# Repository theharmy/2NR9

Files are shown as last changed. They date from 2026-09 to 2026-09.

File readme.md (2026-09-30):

# TwoNr9 (2NR9) is a minimalistic ergonomic 20% Keyboard. 

[Pictures by Purox/Nex](https://ncxy.de/)
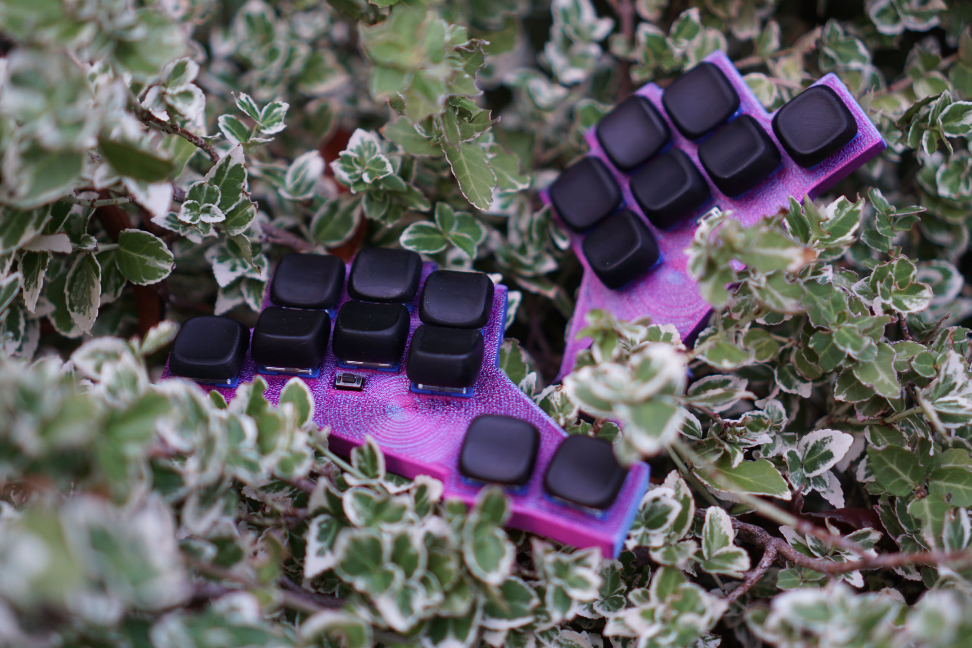
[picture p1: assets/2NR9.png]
2NR9
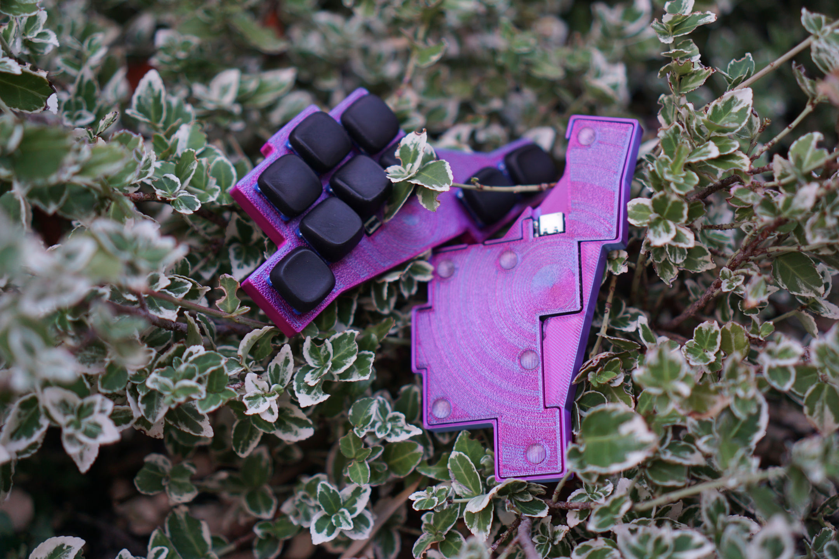
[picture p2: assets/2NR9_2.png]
2NR9_2


## Files In this Repo 
- The PROD files as ZIP as well as a folder, the Kicad PCB File 
- CASE (To-Do)

## Features: 
- 18 Keys with an Minimalistic  Design and Case
- The Case offers hidden Magnet sockets for Magsafe Compability
- Switches: Choc V2 Hotswap 
- MCU: N!N (or Clones)
- battery: 301230 3.7V 110mAh Lipo Battery
  - only this one works due to size Constraints.
- Designed Together with [Purox/Nex](https://ncxy.de/)

### Note 
~~BOTTOM MIDDLE FINGER AND THE PINKY NEED A BODGE WIRE DUE TO WRONGLY FLIPPED HOTSWAP SOCKETS.~~

The Pads for the pinky and bottom middle finger might look odd due to small changes in size, that prevents a bodge wire and should not influence the functionality. 

## ZMK Config: 
- There is a [Blanc Version of the Config](https://github.com/theharmy/zmk-config-twonr9--blank)
- My personal [Config](https://github.com/theharmy/zmk-config), (AI CODE WARNING)
	- with [SRHT by Apfel](https://codeberg.org/apfel)  (A Germlish 2Alpha Layout with Bigrams)
	- and many features of [Urob's ZMK Config](https://github.com/urob/zmk-config) 

### Acknowledgements
- Big Thanks and Much love to 
	- [Purox/Nex](https://ncxy.de/) for a lot of test-printing with me, PCB Design-Support and Feedback.
		- Their: 
			- [Blog](https://ncxy.de/) 
			- [Keyboard Work](https://git.clacktal.es/purox)
			- [Github](https://github.com/ThePurox)
	- Kilipan/Apfel for Getting me Into the 20% Madness, Creation of the SRHT Layout, Patience and Input
		- their:
			- [Codeberg](https://codeberg.org/apfel), for general projects
			- [clacktal.es](https://git.clacktal.es/apfel), for keyboard-related things

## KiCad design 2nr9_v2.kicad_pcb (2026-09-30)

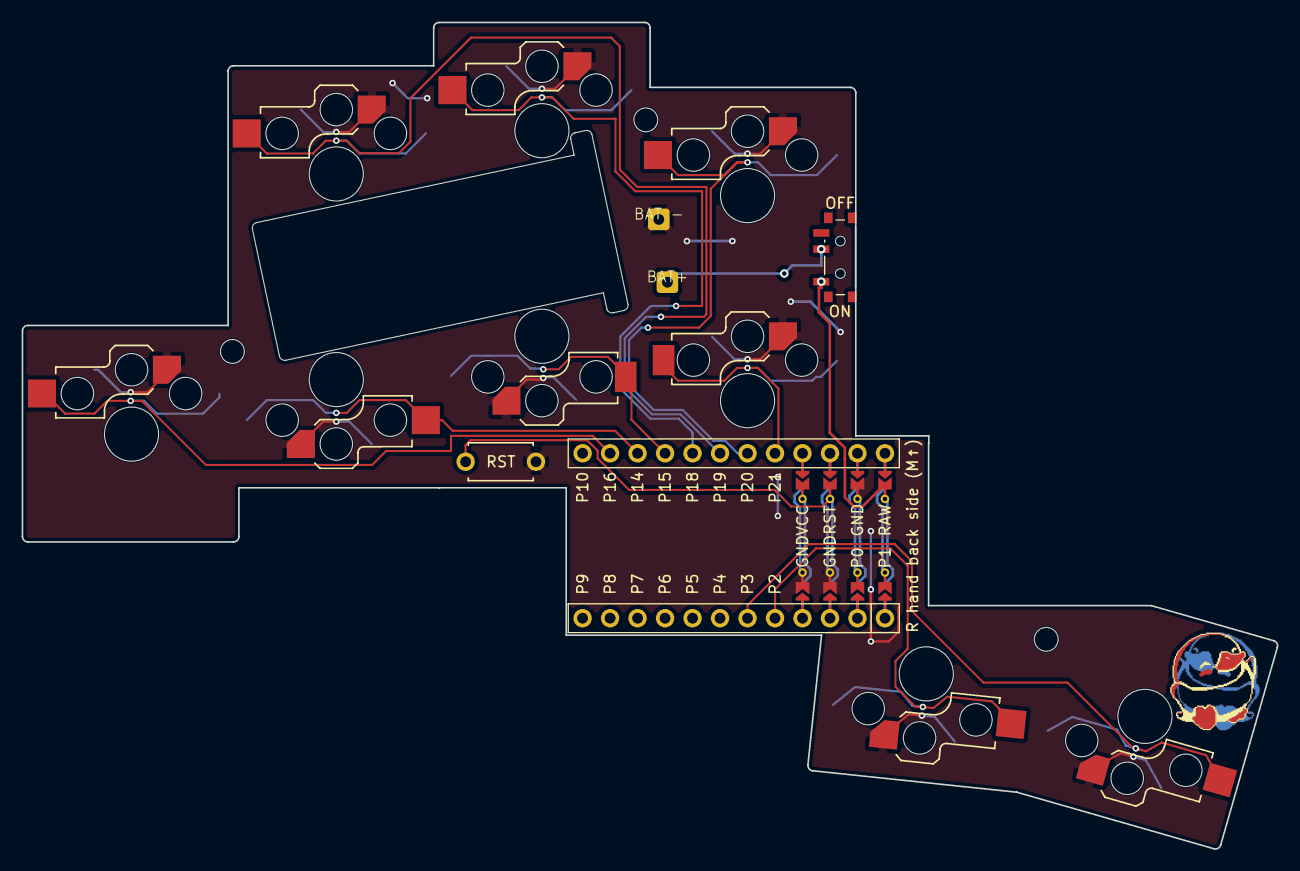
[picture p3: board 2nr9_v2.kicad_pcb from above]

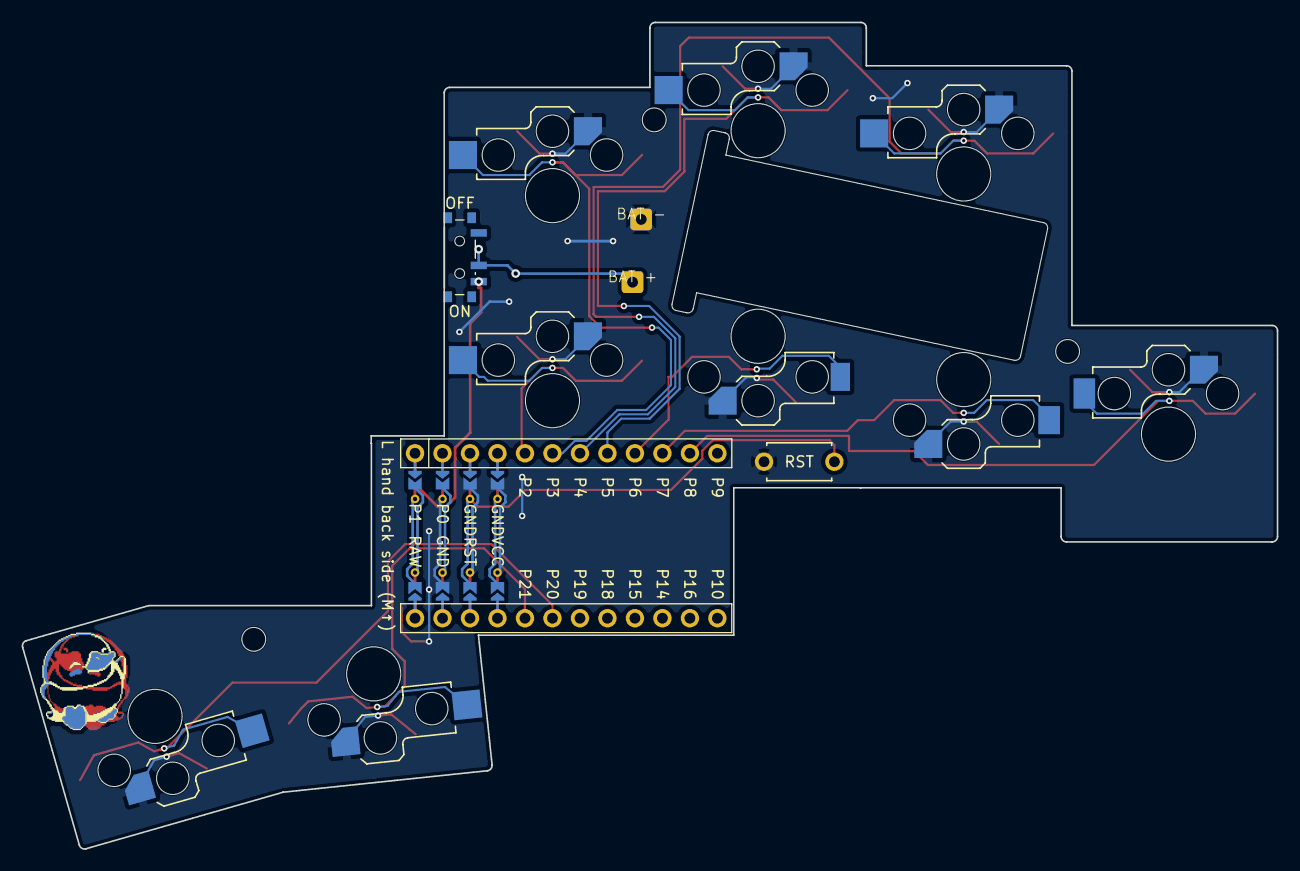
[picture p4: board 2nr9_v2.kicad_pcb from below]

Board: 2 copper layers, 116.0 x 76.4 mm, 19 parts (13 on the bottom side), 13 nets.

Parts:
BAT +: BatteryCablePad
BAT -: BatteryCablePad
BAT -#2: BatteryCablePad
BAT+: BatteryCablePad
MCU1: mcu_nice_nano
MH1, MH2, MH3: mounting_hole_npth
PWR1: power_switch_smd_side
RST1: reset_switch_tht_top
S1, S2, S3, S4, S5, S6, S7, S8, S9: switch_choc_v1_v2

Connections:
BAT_P: BAT +.1, BAT+.1, PWR1.2
GND: BAT -.1, BAT -#2.1, MCU1.103, MCU1.104, MCU1.123, RST1.1, S1.1, S2.1, S3.1, S4.1, S5.1, S6.1, S7.1, S8.1, S9.1
P2: MCU1.5, S8.2
P3: MCU1.6, S9.2
P14: MCU1.15, S2.2
P15: MCU1.16, S4.2
P16: MCU1.14, S1.2
P18: MCU1.17, S5.2
P19: MCU1.18, S3.2
P20: MCU1.19, S7.2
P21: MCU1.20, S6.2
RAW: MCU1.124, PWR1.1, PWR1.3
RST: MCU1.122, RST1.2

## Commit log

2026-09-29 upload repo
    [2nr9.kicad_pcb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]
2026-09-30 Update battery information in README
    Clarify battery specifications for the device.
2026-09-30 fixed PCB
    [2nr9_purox-F_Cu.gbr, 2nr9_v2-B_Cu.gbr, 2nr9_v2-B_Mask.gbr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]
2026-09-30 Update README to clarify wiring and file structure
    Removed the warning about the bodge wire for the bottom middle finger and pinky, and restructured the files section for clarity.
2026-09-30 upload v2 pcb
    [2nr9_v2.kicad_pcb]
